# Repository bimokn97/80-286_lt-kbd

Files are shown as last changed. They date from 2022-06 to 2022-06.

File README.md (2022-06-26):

# 286_lt Mechanical Keyboard
A mechanical keyboard from old laptop called Goldstar GPC-4013B, with STM32F401 blackpill board, and additional serial output SN74HC595.

# choose firmware
  * Diy arduino firmware
      [download](https://github.com/bimokn97/80-286_lt-kbd/blob/master/stmduino_kbd/stmduino_kbd.ino) the .ino file, and open it using arduino software, than flash it.

  * [QMK Firmware](https://github.com/qmk/qmk_firmware.git) 
    * clone the repository     : `git clone https://github.com/bimokn97/qmk_firmware.git`
    * cd to directory          : `cd qmk_firmware`
    * switch to develop branch : `git checkout develop`
    * build it                 : `make 286_lt:default` or `make 286_lt:via` for costumable layout by [via](https://caniusevia.com)
   
   * [Vial Firmware](https://github.com/vial_qmk/vial.git)
     * clone the repository     : `git clone https://github.com/bimokn97/vial_qmk.git`
     * cd to directory          : `cd qmk_firmware`
     * switch to develop branch : `git checkout develop`
     * build it                 : `make 286_lt:vial` for costumable layout by [vial]([https://caniusevia.com](https://get.vial.today/))

# pcb layout and schematic
  using [Kicad](https://www.kicad.org/)
  * [keyboard pcb](https://github.com/bimokn97/80-286_lt-kbd/tree/master/schematic_pcb/keyboard)
  * [mcu connector board](https://github.com/bimokn97/80-286_lt-kbd/tree/master/schematic_pcb/mcu_board)
  
    connector FPC 22 pin 1mm pitch
  
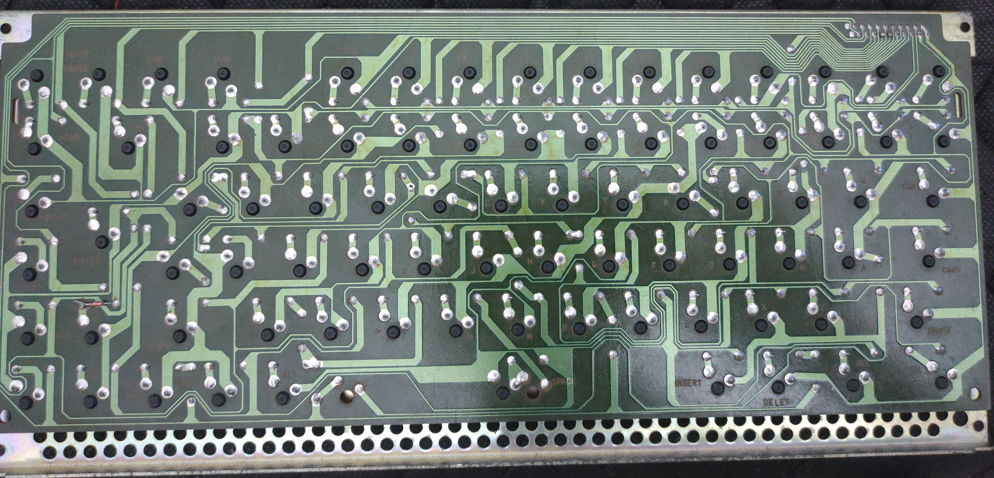
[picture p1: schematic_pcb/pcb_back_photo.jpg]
Photo of back keyboard pcb
  *

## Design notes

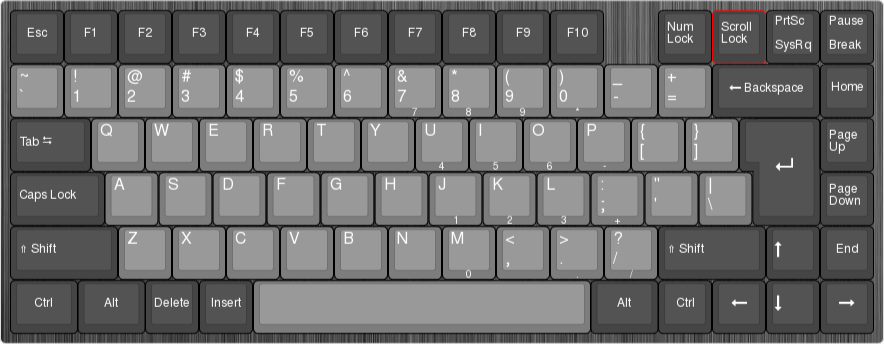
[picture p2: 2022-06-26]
286_lt.png

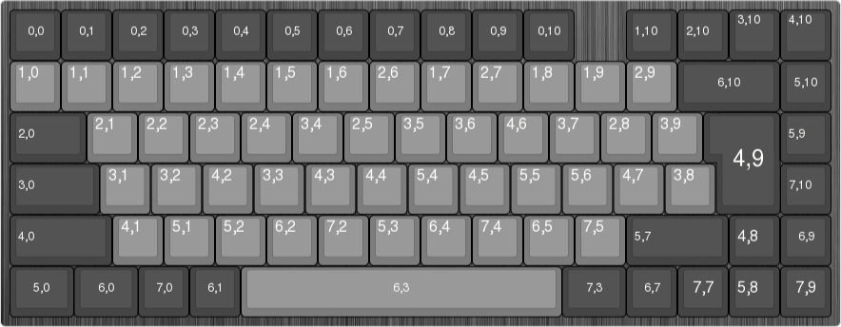
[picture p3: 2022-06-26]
286_lt_via.png

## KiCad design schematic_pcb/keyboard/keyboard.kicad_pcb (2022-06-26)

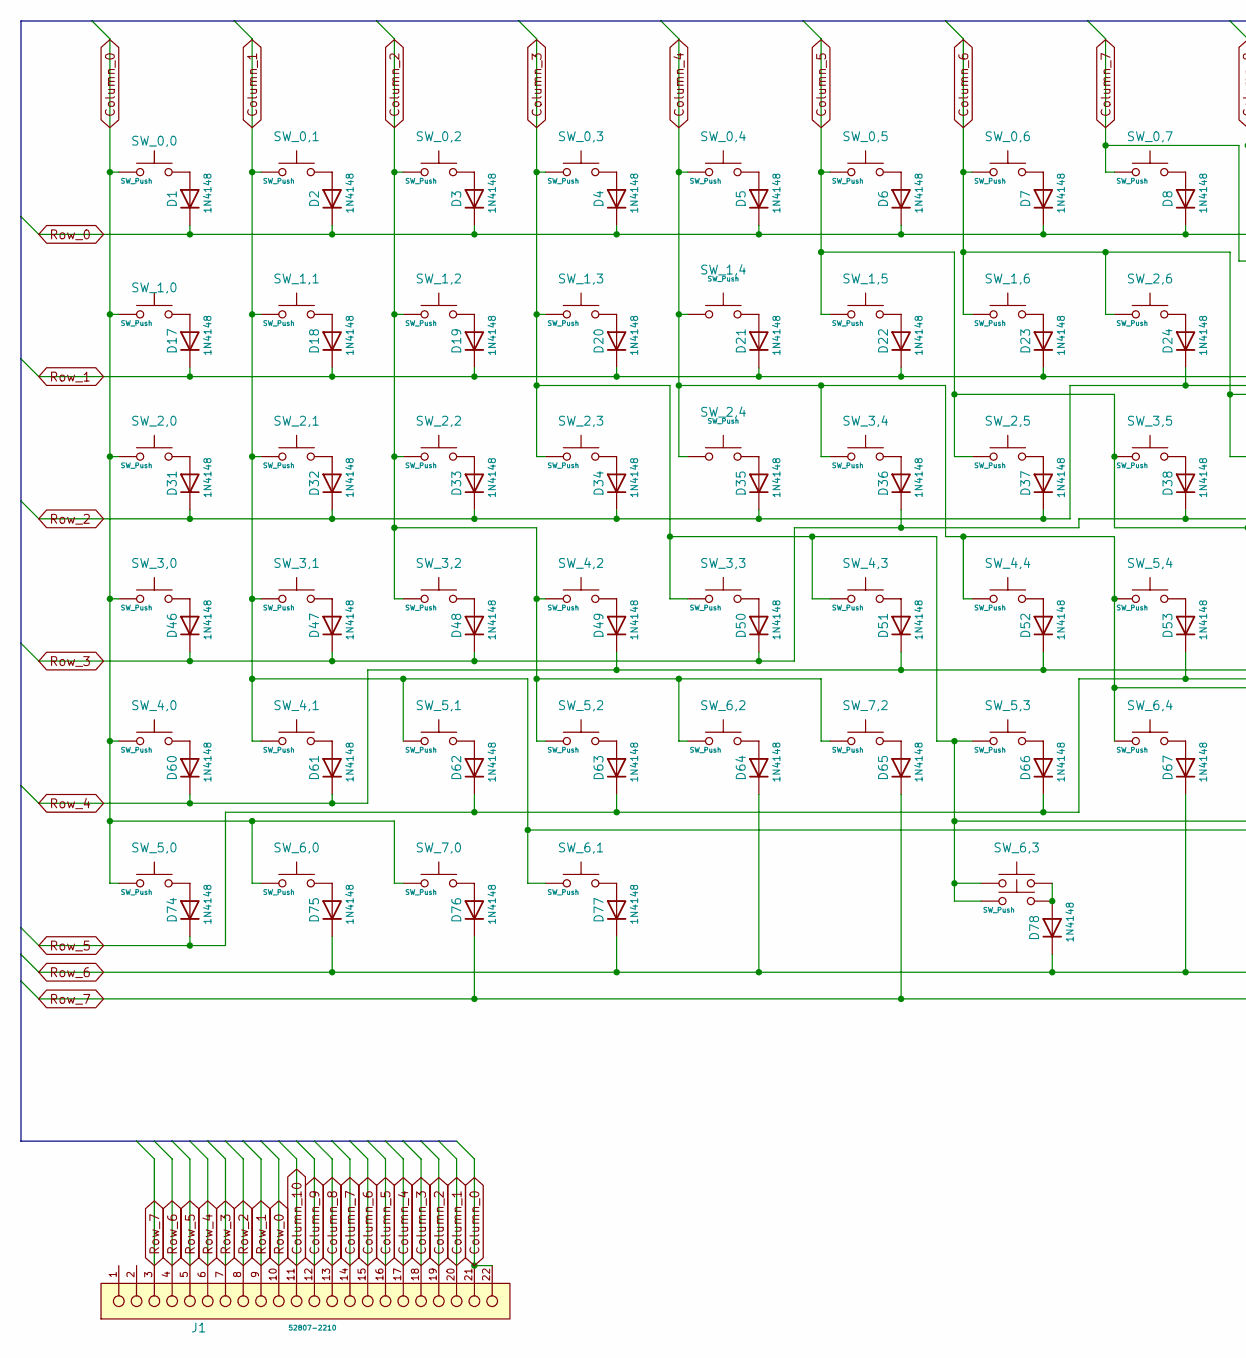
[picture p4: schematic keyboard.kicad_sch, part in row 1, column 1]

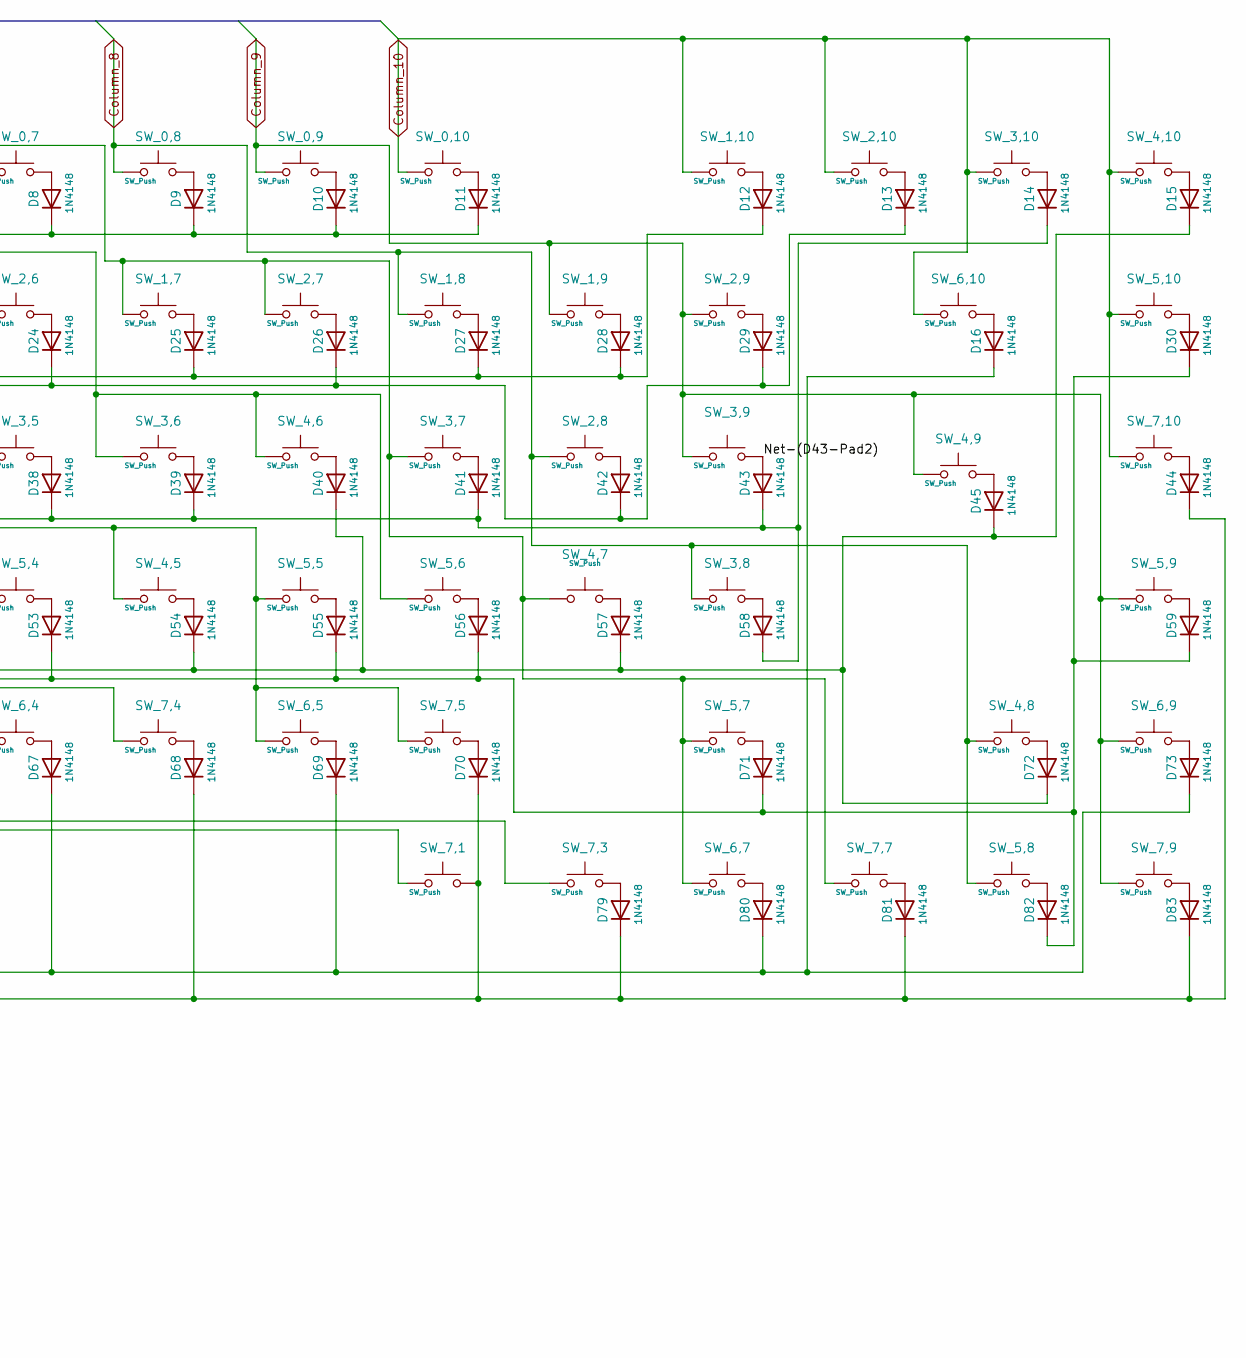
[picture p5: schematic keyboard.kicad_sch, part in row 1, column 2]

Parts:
D1, D2, D3, D4, D5, D6, D7, D8, D9, D10, D11, D12, D13, D14, D15, D16, D17, D18, D19, D20, D21, D22, D23, D24, D25, D26, D27, D28, D29, D30, D31, D32, D36, D37, D38, D39, D40, D41, D42, D45, D46, D47, D48, D49, D50, D54, D55, D56, D57, D60, D61, D62, D63, D64, D65, D66, D67, D68, D69, D70, D71, D72, D76, D77, D79, D80, D81, D82: 1N4148; D_DO-35_SOD27_P12.70mm_Horizontal
D33, D34, D35, D43, D44, D51, D52, D53, D58, D59, D73, D74, D75, D83: 1N4148; D_DO-35_SOD27_P10.16mm_Horizontal
D78: 1N4148; D_DO-35_SOD27_P7.62mm_Horizontal
J1: 52807-2210; Molex-52807-2210-Manufacturer_Recommended; Voltage Max 50V
SW_0,0, SW_0,1, SW_0,2, SW_0,3, SW_0,4, SW_0,5, SW_0,6, SW_0,7, SW_0,8, SW_0,9, SW_0,10, SW_1,0, SW_1,1, SW_1,2, SW_1,3, SW_1,4, SW_1,5, SW_1,6, SW_1,7, SW_1,8, SW_1,9, SW_1,10, SW_2,1, SW_2,2, SW_2,3, SW_2,4, SW_2,5, SW_2,6, SW_2,7, SW_2,8, SW_2,9, SW_2,10, SW_3,1, SW_3,2, SW_3,3, SW_3,4, SW_3,5, SW_3,6, SW_3,7, SW_3,8, SW_3,9, SW_3,10, SW_4,1, SW_4,2, SW_4,3, SW_4,4, SW_4,5, SW_4,6, SW_4,7, SW_4,8, SW_4,10, SW_5,1, SW_5,2, SW_5,3, SW_5,4, SW_5,5, SW_5,6, SW_5,8, SW_5,9, SW_5,10, SW_6,1, SW_6,2, SW_6,4, SW_6,5, SW_6,7, SW_6,9, SW_7,0, SW_7,2, SW_7,3, SW_7,4, SW_7,5, SW_7,7, SW_7,9, SW_7,10: SW_Push; SW_Cherry_MX_Plate_1.00u
SW_2,0: SW_Push; SW_Cherry_MX_Plate_1.50u
SW_3,0, SW_5,7: SW_Push; SW_Cherry_MX_Plate_1.75u
SW_4,0: SW_Push; SW_Cherry_MX_Plate_2.25u
SW_4,9: SW_Push; SW_Cherry_MX_Plate_ISOEnter
SW_5,0, SW_6,0: SW_Push; SW_Cherry_MX_Plate_1.25u
SW_6,3, SW_6,3_1: SW_Push; SW_Cherry_MX_Plate_6.50u
SW_6,10: SW_Push; SW_Cherry_MX_Plate_2.00u
SW_7,1: SW_Push; SW_Cherry_MX_Plate

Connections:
/Net-(D43-Pad2): D43.2 (A), SW_3,9.1
Column_0: J1.21, J1.22, SW_0,0.2, SW_1,0.1, SW_2,0.1, SW_3,0.1, SW_4,0.1, SW_5,0.1, SW_6,0.1, SW_7,0.1
Column_1: J1.20, SW_0,1.1, SW_1,1.1, SW_2,1.1, SW_3,1.1, SW_4,1.1, SW_5,1.1, SW_6,1.1, SW_7,1.1
Column_2: J1.19, SW_0,2.2, SW_1,2.1, SW_2,2.1, SW_3,2.1, SW_4,2.1, SW_5,2.1, SW_6,2.1, SW_7,2.1
Column_3: J1.18, SW_0,3.2, SW_1,3.1, SW_2,3.1, SW_3,3.1, SW_4,3.1, SW_5,3.1, SW_6,3.2, SW_6,3_1.1, SW_7,3.1
Column_4: J1.17, SW_0,4.2, SW_1,4.2, SW_2,4.2, SW_3,4.1, SW_4,4.1, SW_5,4.1, SW_6,4.1, SW_7,4.1
Column_5: J1.16, SW_0,5.2, SW_1,5.1, SW_2,5.1, SW_3,5.1, SW_4,5.1, SW_5,5.1, SW_6,5.1, SW_7,5.1
Column_6: J1.15, SW_0,6.2, SW_1,6.1, SW_2,6.1, SW_3,6.2, SW_4,6.1, SW_5,6.1
Column_7: J1.14, SW_0,7.2, SW_1,7.1, SW_2,7.1, SW_3,7.1, SW_4,7.2, SW_5,7.1, SW_6,7.1, SW_7,7.1
Column_8: J1.13, SW_0,8.2, SW_1,8.1, SW_2,8.1, SW_3,8.1, SW_4,8.1, SW_5,8.1
Column_9: J1.12, SW_0,9.2, SW_1,9.1, SW_2,9.1, SW_3,9.2, SW_4,9.1, SW_5,9.2, SW_6,9.2, SW_7,9.2
Column_10: J1.11, SW_0,10.2, SW_1,10.2, SW_2,10.2, SW_3,10.2, SW_4,10.2, SW_5,10.1, SW_6,10.1, SW_7,10.1
unnamed: D1.2 (A), SW_0,0.1
unnamed: D2.2 (A), SW_0,1.2
unnamed: D3.2 (A), SW_0,2.1
unnamed: D4.2 (A), SW_0,3.1
unnamed: D5.2 (A), SW_0,4.1
unnamed: D6.2 (A), SW_0,5.1
unnamed: D7.2 (A), SW_0,6.1
unnamed: D8.2 (A), SW_0,7.1
unnamed: D9.2 (A), SW_0,8.1
unnamed: D10.2 (A), SW_0,9.1
unnamed: D11.2 (A), SW_0,10.1
unnamed: D12.2 (A), SW_1,10.1
unnamed: D13.2 (A), SW_2,10.1
unnamed: D14.2 (A), SW_3,10.1
unnamed: D15.2 (A), SW_4,10.1
unnamed: D16.2 (A), SW_6,10.2
unnamed: D17.2 (A), SW_1,0.2
unnamed: D18.2 (A), SW_1,1.2
unnamed: D19.2 (A), SW_1,2.2
unnamed: D20.2 (A), SW_1,3.2
unnamed: D21.2 (A), SW_1,4.1
unnamed: D22.2 (A), SW_1,5.2
unnamed: D23.2 (A), SW_1,6.2
unnamed: D24.2 (A), SW_2,6.2
unnamed: D25.2 (A), SW_1,7.2
unnamed: D26.2 (A), SW_2,7.2
unnamed: D27.2 (A), SW_1,8.2
unnamed: D28.2 (A), SW_1,9.2
unnamed: D29.2 (A), SW_2,9.2
unnamed: D30.2 (A), SW_5,10.2
unnamed: D31.2 (A), SW_2,0.2
unnamed: D32.2 (A), SW_2,1.2
unnamed: D33.2 (A), SW_2,2.2
unnamed: D34.2 (A), SW_2,3.2
unnamed: D35.2 (A), SW_2,4.1
unnamed: D36.2 (A), SW_3,4.2
unnamed: D37.2 (A), SW_2,5.2
unnamed: D38.2 (A), SW_3,5.2
unnamed: D39.2 (A), SW_3,6.1
unnamed: D40.2 (A), SW_4,6.2
unnamed: D41.2 (A), SW_3,7.2
unnamed: D42.2 (A), SW_2,8.2
unnamed: D44.2 (A), SW_7,10.2
unnamed: D45.2 (A), SW_4,9.2
unnamed: D46.2 (A), SW_3,0.2
unnamed: D47.2 (A), SW_3,1.2
unnamed: D48.2 (A), SW_3,2.2
unnamed: D49.2 (A), SW_4,2.2
unnamed: D50.2 (A), SW_3,3.2
unnamed: D51.2 (A), SW_4,3.2
unnamed: D52.2 (A), SW_4,4.2
unnamed: D53.2 (A), SW_5,4.2
unnamed: D54.2 (A), SW_4,5.2
unnamed: D55.2 (A), SW_5,5.2
unnamed: D56.2 (A), SW_5,6.2
unnamed: D57.2 (A), SW_4,7.1
unnamed: D58.2 (A), SW_3,8.2
unnamed: D59.2 (A), SW_5,9.1
unnamed: D60.2 (A), SW_4,0.2
unnamed: D61.2 (A), SW_4,1.2
unnamed: D62.2 (A), SW_5,1.2
unnamed: D63.2 (A), SW_5,2.2
unnamed: D64.2 (A), SW_6,2.2
unnamed: D65.2 (A), SW_7,2.2
unnamed: D66.2 (A), SW_5,3.2
unnamed: D67.2 (A), SW_6,4.2
unnamed: D68.2 (A), SW_7,4.2
unnamed: D69.2 (A), SW_6,5.2
unnamed: D70.2 (A), SW_7,5.2
unnamed: D71.2 (A), SW_5,7.2
unnamed: D72.2 (A), SW_4,8.2
unnamed: D73.2 (A), SW_6,9.1
unnamed: D74.2 (A), SW_5,0.2
unnamed: D75.2 (A), SW_6,0.2
unnamed: D76.2 (A), SW_7,0.2
unnamed: D77.2 (A), SW_6,1.2
unnamed: D78.2 (A), SW_6,3.1, SW_6,3_1.2
unnamed: D79.2 (A), SW_7,3.2
unnamed: D80.2 (A), SW_6,7.2
unnamed: D81.2 (A), SW_7,7.2
unnamed: D82.2 (A), SW_5,8.2
unnamed: D83.2 (A), SW_7,9.1
Row_0: D1.1 (K), D2.1 (K), D3.1 (K), D4.1 (K), D5.1 (K), D6.1 (K), D7.1 (K), D8.1 (K), D9.1 (K), D10.1 (K), D11.1 (K), J1.10
Row_1: D12.1 (K), D17.1 (K), D18.1 (K), D19.1 (K), D20.1 (K), D21.1 (K), D22.1 (K), D23.1 (K), D25.1 (K), D27.1 (K), D28.1 (K), J1.9
Row_2: D13.1 (K), D24.1 (K), D26.1 (K), D29.1 (K), D31.1 (K), D32.1 (K), D33.1 (K), D34.1 (K), D35.1 (K), D37.1 (K), D42.1 (K), J1.8
Row_3: D14.1 (K), D36.1 (K), D38.1 (K), D39.1 (K), D41.1 (K), D43.1 (K), D46.1 (K), D47.1 (K), D48.1 (K), D50.1 (K), D58.1 (K), J1.7
Row_4: D15.1 (K), D40.1 (K), D45.1 (K), D49.1 (K), D51.1 (K), D52.1 (K), D54.1 (K), D57.1 (K), D60.1 (K), D61.1 (K), D72.1 (K), J1.6
Row_5: D30.1 (K), D53.1 (K), D55.1 (K), D56.1 (K), D59.1 (K), D62.1 (K), D63.1 (K), D66.1 (K), D71.1 (K), D74.1 (K), D82.1 (K), J1.5
Row_6: D16.1 (K), D64.1 (K), D67.1 (K), D69.1 (K), D73.1 (K), D75.1 (K), D77.1 (K), D78.1 (K), D80.1 (K), J1.4
Row_7: D44.1 (K), D65.1 (K), D68.1 (K), D70.1 (K), D76.1 (K), D79.1 (K), D81.1 (K), D83.1 (K), J1.3, SW_7,1.2

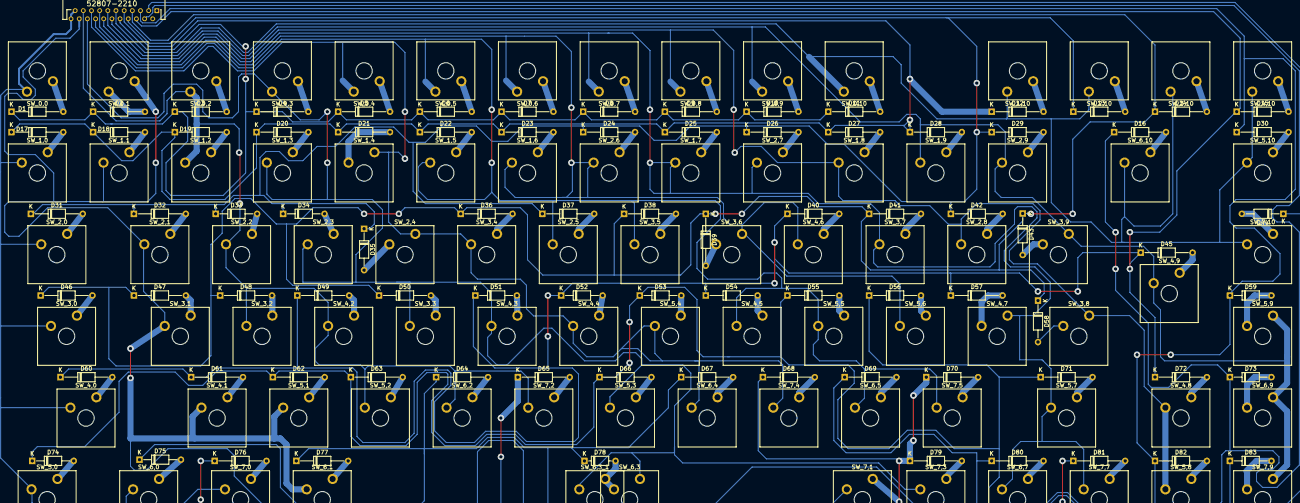
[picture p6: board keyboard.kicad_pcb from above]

Board: 2 copper layers, 169 parts (0 on the bottom side), 102 nets.

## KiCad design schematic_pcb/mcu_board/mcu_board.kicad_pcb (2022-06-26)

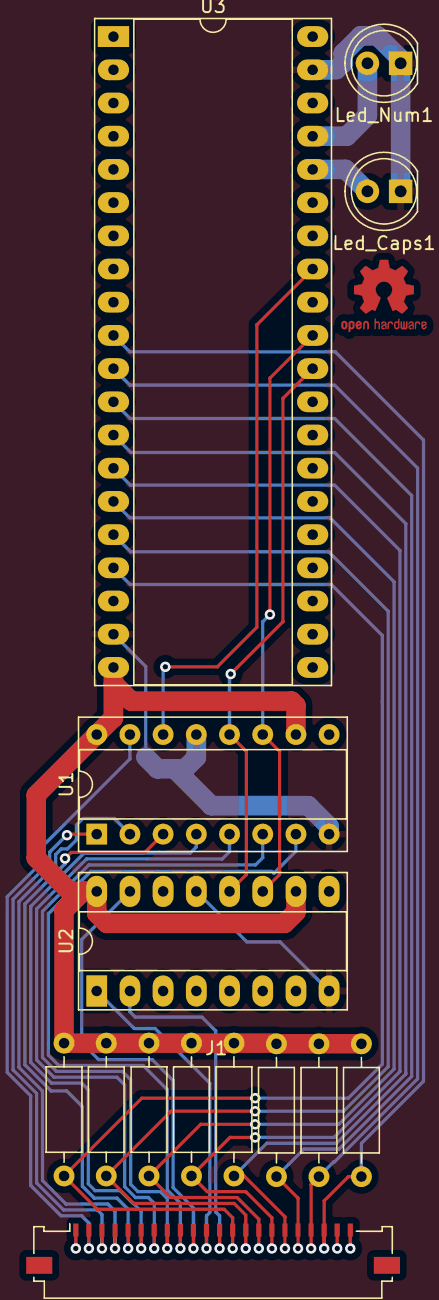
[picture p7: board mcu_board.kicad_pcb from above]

Board: 2 copper layers, 14 parts (0 on the bottom side), 27 nets.

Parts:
J1: Conn_01x22; Molex_200528-0220_1x22-1MP_P1.00mm_Horizontal
Led_Caps1: LED; LED_D5.0mm
Led_Num1: LED; LED_D5.0mm
R1, R2, R3, R4, R5, R6, R7, R8: R 10 kΩ; R_Axial_DIN0207_L6.3mm_D2.5mm_P10.16mm_Horizontal
U1: 74HC595; DIP-16_W7.62mm_Socket
U2: 74HC595; DIP-16_W7.62mm_Socket_LongPads
U3: YAAJ_BlackPill_Part_Like; DIP-40_W15.24mm_Socket_LongPads

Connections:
+3V3: R1.2, R2.2, R3.2, R4.2, R5.2, R6.2, R7.2, R8.2, U1.10 (~SRCLR), U1.16 (VCC), U2.10 (~SRCLR), U2.16 (VCC), U3.20 (3V3)
Column_0: J1.2, U1.15 (QA)
Column_1: J1.3, U1.1 (QB)
Column_2: J1.4, U1.2 (QC)
Column_3: J1.5, U1.3 (QD)
Column_4: J1.6, U1.4 (QE)
Column_5: J1.7, U1.5 (QF)
Column_6: J1.8, U1.6 (QG)
Column_7: J1.9, U1.7 (QH)
Column_8: J1.10, U2.15 (QA)
Column_9: J1.11, U2.1 (QB)
Column_10: J1.12, U2.2 (QC)
GND: Led_Caps1.1 (K), Led_Num1.1 (K), U1.8 (GND), U1.13 (~OE), U2.8 (GND), U2.13 (~OE), U3.19 (GND), U3.39 (GND)
unnamed: Led_Caps1.2 (A), U3.36 (PB2)
unnamed: Led_Num1.2 (A), U3.37 (PB10)
unnamed: U1.9 (QH'), U2.14 (SER)
Row_0: J1.13, R1.1, U3.17 (PB9)
Row_1: J1.14, R2.1, U3.16 (PB8)
Row_2: J1.15, R3.1, U3.15 (PB7)
Row_3: J1.16, R4.1, U3.14 (PB6)
Row_4: J1.17, R5.1, U3.13 (PB5)
Row_5: J1.18, R6.1, U3.12 (PB4)
Row_6: J1.19, R7.1, U3.11 (PB3)
Row_7: J1.20, R8.1, U3.10 (PA15)
SPI_74HC595_SS: U1.12 (RCLK), U2.12 (RCLK), U3.30 (PA4)
SPI_MOSI: U1.14 (SER), U3.33 (PA7)
SPI_SCLK/CLK: U1.11 (SRCLK), U2.11 (SRCLK), U3.31 (PA5)

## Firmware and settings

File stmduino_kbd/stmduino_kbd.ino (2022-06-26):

#include <Keyboard.h>
#include <SPI.h>
#include <Arduino.h>
#include <inttypes.h>

const uint8_t SS589 = PA1
const uint8_t LS589 =  PA2


/* PA10 - PA12 used for USB */
const uint8_t rowsPin[] = { PB9, PB8, PB7, PB6, PB5, PB4, PB3, PA15 };
const int rowCount = sizeof(rowsPin) / sizeof(rowsPin[0]);
//uint16_t rowData[] = { 0x0001, 0x0002, 0x0004, 0x0008, 0x0010, 0x0020, 0x0040, 0x0080, 0x0100};
//const int rowCount = sizeof(rowData) / sizeof(rowData[0]);

/*
     this data is configure 74hc595 pin on binary
     i set all hc595 pin high, and selected pin to low
     because it used 2 hc595, so i use 16 bit data on it
*/
//const uint8_t colsPin[] = {PB9, PB8, PB7, PB6, PB5, PB4, PB3, PA15, PA9, PA8, PB15 };
//const int colCount = sizeof(colsPin) / sizeof(colsPin[0]);
uint16_t colData[] = { 0x0001, 0x0002, 0x0004, 0x0008, 0x0010, 0x0020, 0x0040, 0x0080, 0x0100, 0x200, 0x0400 };
const int colCount = sizeof(colData) / sizeof(colData[0]);

/*
   This data contain all preconfigured keys

  String keys[8][11] = {
  {"Escape", "F1", "F2", "F3", "F4", "F5", "F6", "F7", "F8", "F9", "F10"},
  {"`", "1", "2", "3", "4", "5", "6", "8", "0", "-", "Numlock"},
  {"TAB", "q", "w", "e", "r", "y", "7", "9", "[", "=", "ScrollLock"},
  {"Capslock", "a", "s", "f", "t", "u", "i", "p", "|", "}", "PrintScreen"},
  {"LShift", "z", "d", "g", "h", "k", "o", "'", "UArrow", "Enter", "PauseBreak"},
  {"LCtrl", "x", "c", "n", "j", "l", ";", "RShift", "DArrow", "PgDown", "Home"},
  {"LAlt", "Insert", "v", "Space", "m", ".", "XX", "RCtrl", "XX", "End", "BackSpace"},
  {"Delete", "XX", "b", "RAlt", ",", "/", "XX", "LArrow", "XX", "RArrow", "PgUp"},
  };
*/

/* and this is key in ascii
   https://www.arduino.cc/reference/en/language/functions/usb/keyboard/keyboardmodifiers/
*/
byte keys[rowCount][colCount] = {
  {0xB1, 0xC2, 0xC3, 0xC4, 0xC5, 0xC6, 0xC7, 0xC8, 0xC9, 0xCA, 0xCB},
  {0x7E, 0x31, 0x32, 0x33, 0x34, 0x35, 0x36, 0x38, 0x30, 0x2D, 0xDB},
  {0xB3, 0x71, 0x77, 0x65, 0x72, 0x79, 0x37, 0x39, 0x5B, 0x3D, 0xCF},
  {0xC1, 0x61, 0x73, 0x66, 0x74, 0x75, 0x69, 0x70, 0x5C, 0x5D, 0xCE},
  {0x81, 0x7A, 0x64, 0x67, 0x68, 0x6B, 0x6F, 0x27, 0xDA, 0xB0, 0xD0},
  {0x80, 0x78, 0x63, 0x6E, 0x6A, 0x6C, 0x3B, 0x85, 0xD9, 0xD6, 0xD2},
  {0x82, 0xD1, 0x76, 0x20, 0x6D, 0x2E, 0x00, 0x84, 0x00, 0xD5, 0xB2},
  {0xD4, 0x00, 0x62, 0x86, 0x2C, 0x2F, 0x00, 0xD8, 0x00, 0xD7, 0xD3},
};

bool keysState[rowCount][colCount];
bool keysPrevState[rowCount][colCount];
uint32_t keyslastDebounce[rowCount][colCount];
uint16_t debounceDelay = 50;

String str;
int col = 0, row = 0;
uint16_t data;
String state[] = {"release", "pressed"};
uint16_t* spi_buffer;


namespace myKbd {
void begin() {
  pinMode(SS595, OUTPUT);
  digitalWrite(SS595, HIGH);

  // initialize keyboard pin
  for (auto pin : rowsPin) {
    pinMode(pin, INPUT_PULLUP);
    /* no longger used, move to hc595
      for (col = 0; col < colCount; col++) {
      //set column pin to output and set to high
      pinMode(colsPin[col], OUTPUT);
      digitalWrite(colsPin[col], HIGH);

      // set all keystate and pre state to 1
      keysState[row][col] = 1;
      keysPrevState[rowCount][colCount] = 1 ;
      //}
    */
  }
}

void keyReads() {
  int col = 0, row = 0;
  /*
    set hc595 pinout using spi
    spi_buff = 0xF7FF; 1111111111101111
  */

  //scan each column
  for (col = 0; col < colCount; col++) {
    //set col high
    //digitalWrite(colsPin[col], LOW);

    //send 16 bit spi
    data = ~colData[col];
    digitalWrite(SS595, LOW);
    *spi_buffer = SPI.transfer16(data);
    digitalWrite(SS595, HIGH);

    // scan each row
    for (row = 0; row < rowCount; row++) {
      //read keyboard row
      keysState[row][col] = !digitalRead(rowsPin[row]);

      /* inverting register and shift to right */
      //spi_buff = ~spi_buff;
      //spi_buff = spi_buff << 1;
      //spi_buff = ~spi_buff;

      //set col high /* used only if using mcu io */
      //digitalWrite(colsPin[col], HIGH);
    }
  }
}

void keyProccess() {
  int col = 0, row = 0;
  for (col = 0; col < colCount; col++) {
    for (row = 0; row < rowCount; row++) {
      // if keyboard pressed internal led on
      if (keysState[row][col]) {
        digitalWrite(LED_BUILTIN, LOW);
      }

      //if ((millis() - keyslastDebounce[row][col]) > debounceDelay) {
      if (keysState[row][col] != keysPrevState[row][col]) {

        //#ifdef KEYBOARD_h
        if ( keysState[row][col] ) {
          Keyboard.press(keys[row][col]);
        } else {
          Keyboard.release(keys[row][col]);
        }
        //#endif
#ifdef SERIAL_H
        Serial.printf("Row|Col: [%02d][%02d] | Ascii key: 0x%02X | State: %s | Time; %03d ms \r \n", row, col, keys[row][col], state[keysState[row][col]].c_str(), millis() -  keyslastDebounce[row][col]);
#endif
      }

      if (keysState[row][col] != keysPrevState[row][col]) {
        keyslastDebounce[row][col] = millis();
      }

      keysPrevState[row][col] = keysState[row][col];
    }
  }

}
}

char h_str[3];
char m_str[3];

long lastTime = 0;
long s = 0;
long m = 0;
long h = 0;
bool sec;

void setup() {
  // initialize the LED pin as an output:
  pinMode(LED_BUILTIN, OUTPUT);
  digitalWrite(LED_BUILTIN, HIGH);

  pinMode(PB10, OUTPUT);
  digitalWrite(PB10, LOW);

  pinMode(USER_BTN, INPUT_PULLUP);

  pinMode(SSEEPROM, OUTPUT);
  digitalWrite(SSEEPROM, HIGH);

  //SPI.setClockDivider(SPI_CLOCK_DIV16);

  myKbd::begin();

  SPI.begin();

  //#ifdef KEYBOARD_h
  Keyboard.begin();
  //#endif

#ifdef SERIAL_H
  Serial.begin(115200);
  Serial.println("Started kbd");
#endif
}


void loop() {
  myKbd::keyReads();
  myKbd::keyProccess();
  digitalWrite(SS595, HIGH);
  digitalWrite(LED_BUILTIN, HIGH);

}
